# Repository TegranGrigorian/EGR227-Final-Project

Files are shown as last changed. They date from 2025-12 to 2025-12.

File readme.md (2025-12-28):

# EGR 227 Final Project

This project is a simple arcade machine using embedded microcontroller **PIC18F56Q71** to run two games: a target shooting game and a Simon Says memory game. The project utilizes various peripherals including buttons, a keypad, an LCD display, RGB LEDs, a servo motor, and a speaker to create an interactive gaming experience. This repository contains the source code, hardware schematics, and documentation for the project. Using this repository a user can build and run the arcade machine on their own hardware setup. 

## Images of the Project

### Project Model in Solidworks

This is a Solidworks assembly model of the project without any electronical components or wiring; just the 3D printed shells for the project.

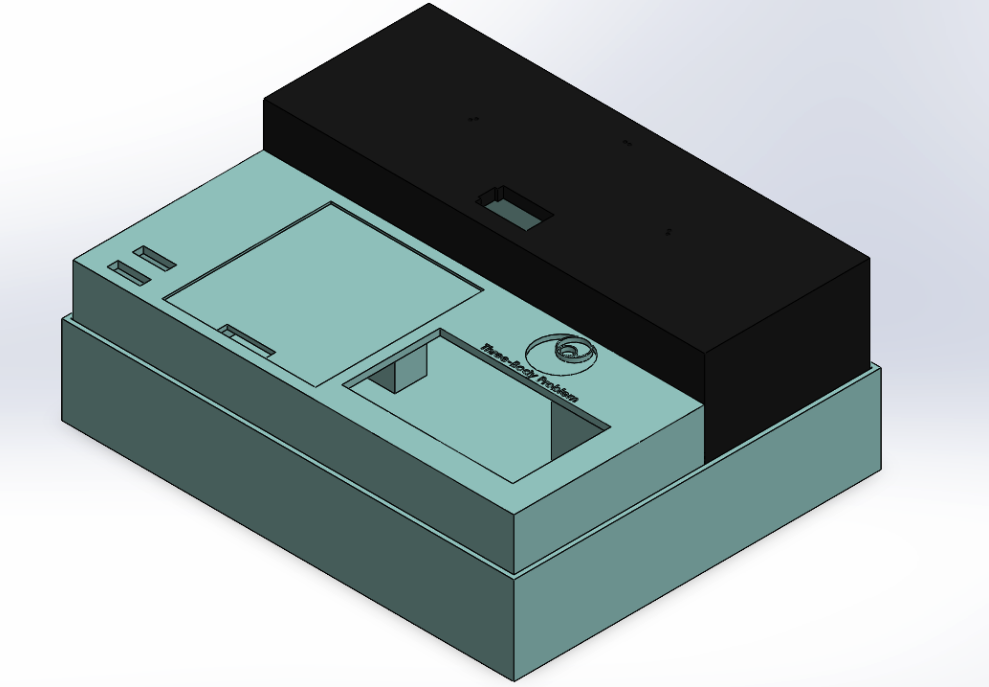
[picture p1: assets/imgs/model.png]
Project Model


### Project In Real Life

This is an image of the completed project with all the electronic components.

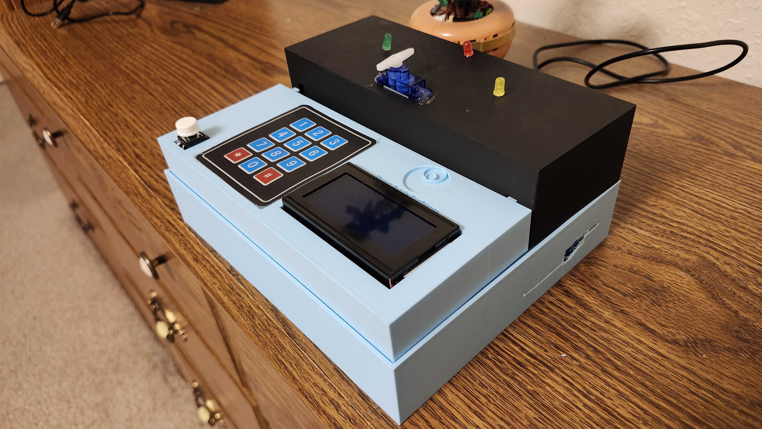
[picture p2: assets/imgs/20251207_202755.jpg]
Project Image


### Electrical Schematic

This is the electrical schematic of the project created using KICAD.

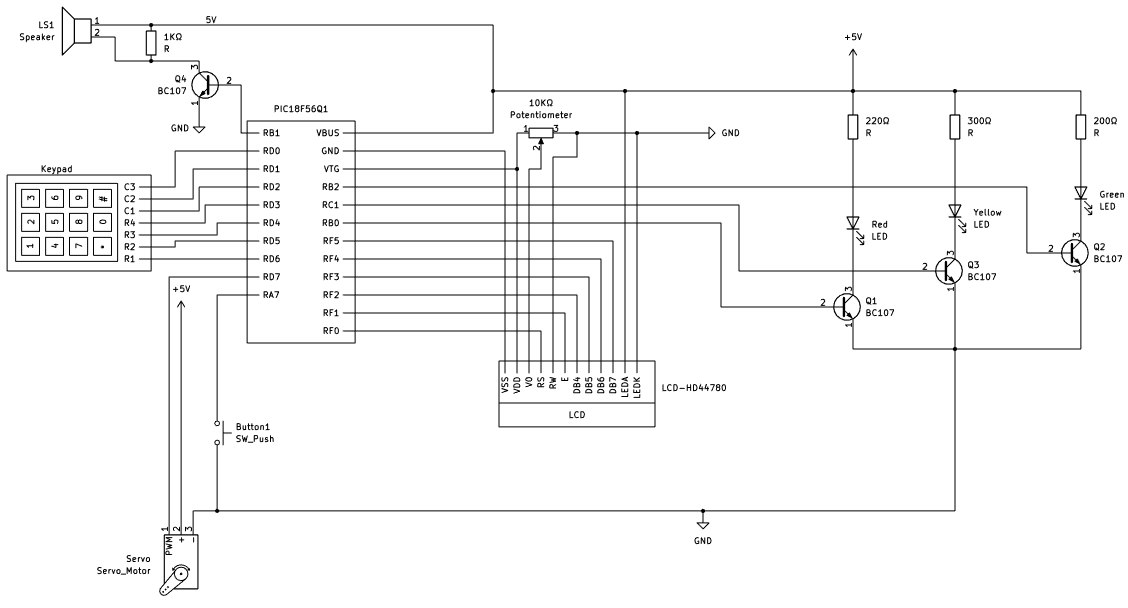
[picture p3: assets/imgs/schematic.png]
Schematic Image


### State Diagram

This is the final state diagram of the project showing all the states and transitions between them.

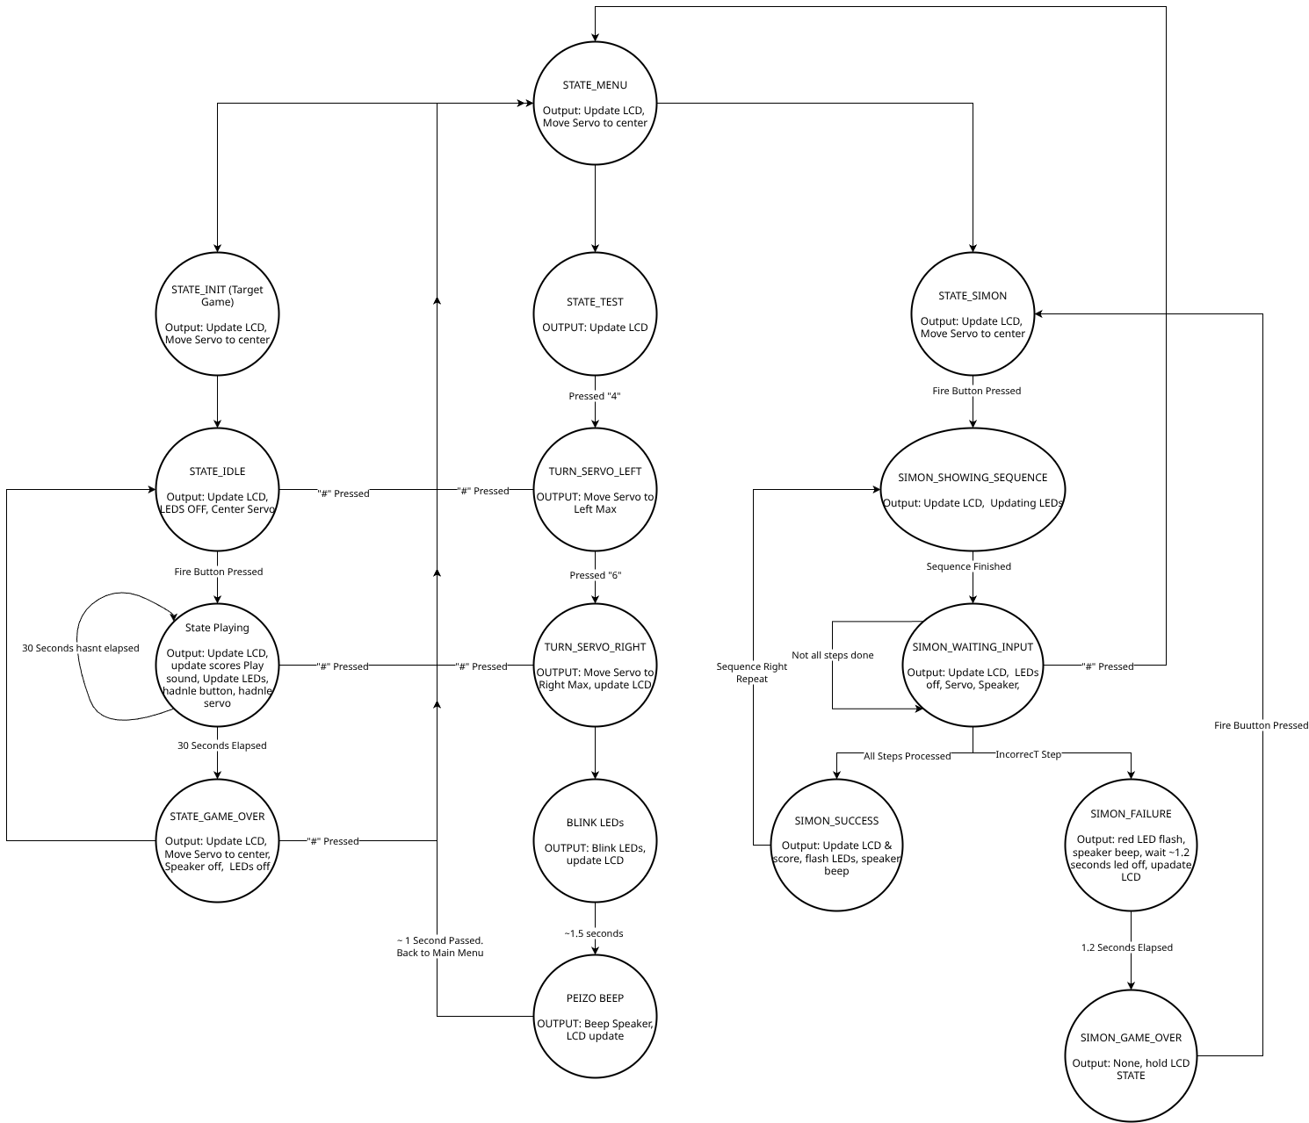
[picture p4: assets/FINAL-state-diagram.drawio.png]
State Diagram


## Project Structure

### File Tree

```
├── assets
│   ├── imgs
│   │   ├── 20251207_191956.jpg
│   │   ├── 20251207_192033.jpg
│   │   ├── 20251207_192102.jpg
│   │   ├── 20251207_192118.jpg
│   │   ├── 20251207_192130.jpg
│   │   ├── 20251207_192202.jpg
│   │   ├── 20251207_192209.jpg
│   │   ├── 20251207_192219.jpg
│   │   ├── 20251207_202755.jpg
│   │   ├── model.png
│   │   └── schematic.png
│   ├── models
│   │   ├── Assembly_all.SLDASM
│   │   ├── floor.SLDPRT
│   │   ├── floor.STL
│   │   ├── input-table.SLDPRT
│   │   ├── input-table.STL
│   │   ├── led-servo_table.SLDPRT
│   │   └── led-servo_table.STL
│   ├── FINAL-state-diagram.drawio.png
│   ├── GUI-state-diagram.drawio.png
│   ├── SIMON-state-diagram.drawio.png
│   ├── STATE_PLAYING.drawio.png
│   ├── target-game-state-diagram.drawio.png
│   └── TEST-state-diagram.drawio.png
├── schematic
│   ├── hd44780.kicad_sym
│   ├── schematic.kicad_pcb
│   ├── schematic.kicad_prl
│   ├── schematic.kicad_pro
│   └── schematic.kicad_sch
├── src
│   ├── button
│   │   ├── button.c
│   │   └── button.h
│   ├── gui
│   │   ├── gui.c
│   │   └── gui.h
│   ├── keypad
│   │   ├── keypad.c
│   │   └── keypad.h
│   ├── lcd
│   │   ├── lcd.c
│   │   └── lcd.h
│   ├── led
│   │   ├── led.c
│   │   └── led.h
│   ├── servo
│   │   ├── servo.c
│   │   └── servo.h
│   ├── simon
│   │   ├── simon.c
│   │   └── simon.h
│   ├── speaker
│   │   ├── speaker.c
│   │   └── speaker.h
│   ├── state
│   │   ├── state.c
│   │   └── state.h
│   ├── test
│   │   ├── test.c
│   │   └── test.h
│   ├── timer
│   │   ├── timer.c
│   │   └── timer.h
│   ├── hardware.h
│   ├── main.c
│   └── readme.md
├── readme.md
├── report.pdf
└── schematic.pdf
```

### Folders
- `src`: Contains all source code files for the project, including C source files and header files.
- `assets`: Contains images and state diagrams used in the project documentation.
- `schematic`: contains the KICAD schematic files for the hardware design.

### Files
- `readme.md`: This file, providing an overview of the project structure and module descriptions
- `report.pdf`: The final project report detailing the design, implementation, and testing of the project.
- `schematic.pdf`: A PDF export of the KICAD schematic for easy viewing.

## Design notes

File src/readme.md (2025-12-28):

# Project File Organization

## Directory Structure

```
├── button/
├── gui/
├── keypad/
├── lcd/
├── led/
├── servo/
├── simon/
├── speaker/
├── state/
├── test/
└── timer/
├── hardware.h
└── main.c
```

## Module Descriptions

### **button**
Handles initialization and processing of the fire button input. Provides debouncing logic and input detection to trigger game state transitions and gameplay mechanics.

### **gui**
Manages the graphical user interface state machine, including menu navigation and visual feedback. Handles state output logic and transitions between different GUI screens (splash screen, main menu, game over menu).

### **hardware.h**
Central repository for all hardware pin definitions and peripheral configurations. Provides a single source of truth for GPIO pin mappings, timer channels, PWM outputs, and device addresses used throughout the project.

### **keypad**
Implements keypad initialization and input processing for the 4x4 matrix keypad. Scans rows and columns, debounces inputs, and stores detected key presses in a structured format for game logic consumption.

### **lcd**
Provides comprehensive LCD control functions for a 16x2 character display. Includes initialization, data transmission, cursor positioning, and string writing capabilities. Manages timing delays required by HD44780 controller protocol.

### **led**
Handles RGB LED initialization and control. Includes functions to set LED colors, implement visual modes (GREEN_RED_YELLOW, YELLOW_RED_GREEN, RANDOM_STATIC), and update display patterns during gameplay. Defines LED enumeration types for mode selection.

### **main.c**
Contains the primary state machine orchestrator that coordinates the entire program flow. Initializes all peripherals and executes the main game loop, dispatching to appropriate handlers based on current program state.

### **servo**
Manages servo motor initialization and position control via PWM. Stores an array of predefined servo positions (POS_1 through POS_5) and provides functions to update duty cycles, enabling dynamic servo movement during gameplay.

### **simon**
Implements the Simon Says memory game logic. Contains initialization code to reset game state, multiple state handlers for game phases (SHOWING_SEQUENCE, WAITING_INPUT, SUCCESS, FAILURE), and a holistic game orchestrator that manages the complete Simon Says gameplay loop.

### **speaker**
Handles speaker initialization and audio control via PWM frequency modulation. Provides functions to generate sound effects and tones of varying frequencies and durations, used by both the target game and Simon Says game for audio feedback.

### **state**
Implements the target game state machine with four primary states (INIT, IDLE, PLAYING, GAME_OVER). Includes state handler functions that manage game initialization, idle waiting, active gameplay, and score display. Coordinates interactions with LED, servo, speaker, keypad, and LCD modules.

### **test**
Contains hardware diagnostic and testing functions that verify proper operation of all peripheral devices including buttons, keypads, LEDs, servos, speakers, and LCD displays. Used for development debugging and hardware validation.

### **timer**
Manages timer initialization and interrupt handling. Implements Timer 0 for precise 10 ms interrupt generation (100 interrupts per second), Timer 1 for blocking delays, and Timer 2/4 for PWM control. The Timer 0 ISR enforces the 30-second game duration by counting elapsed seconds.

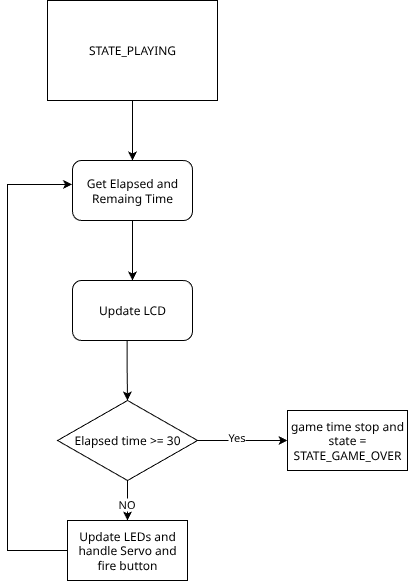
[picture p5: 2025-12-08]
assets/STATE_PLAYING.drawio.png

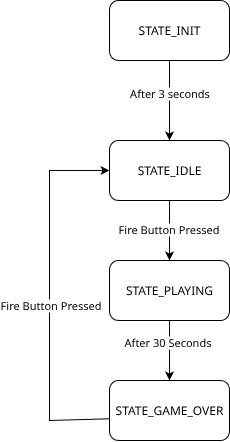
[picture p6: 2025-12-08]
assets/target-game-state-diagram.drawio.png

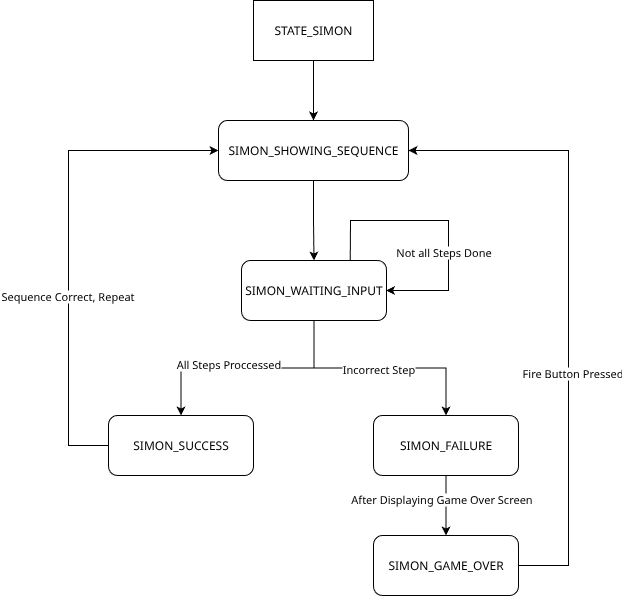
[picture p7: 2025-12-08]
assets/SIMON-state-diagram.drawio.png

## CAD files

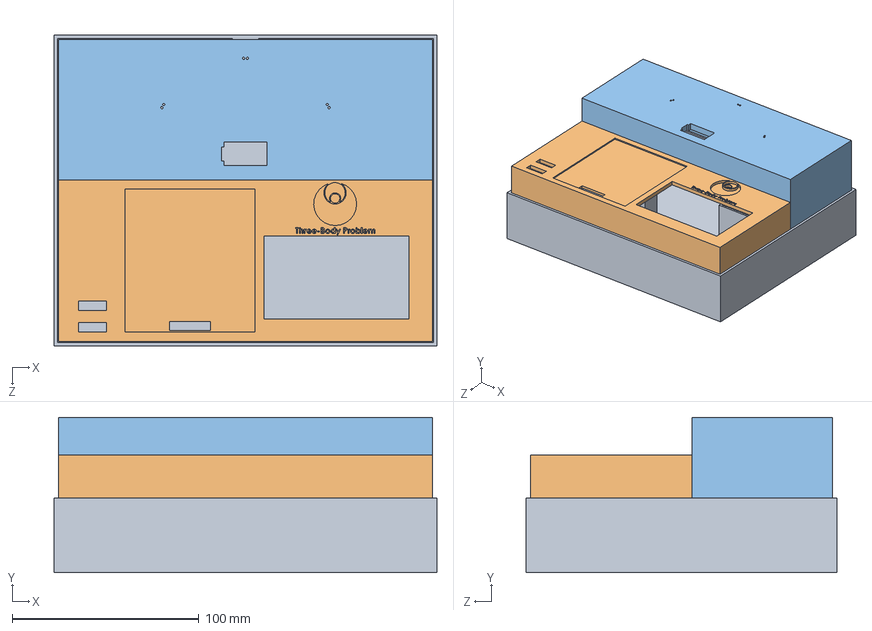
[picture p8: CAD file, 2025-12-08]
assets/models/Assembly_all.SLDASM
205.0 x 83.0 x 166.5 mm
led-servo_table
input-table
floor

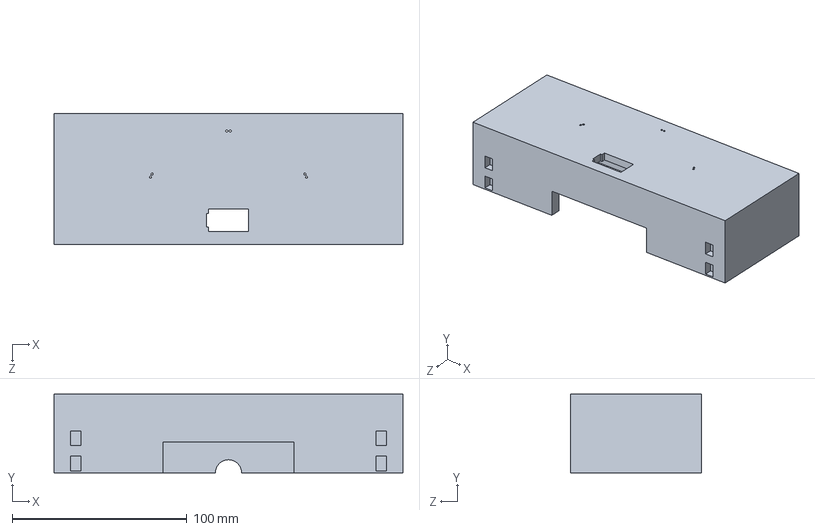
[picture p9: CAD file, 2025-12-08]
assets/models/led-servo_table.SLDPRT
200.0 x 45.0 x 75.0 mm

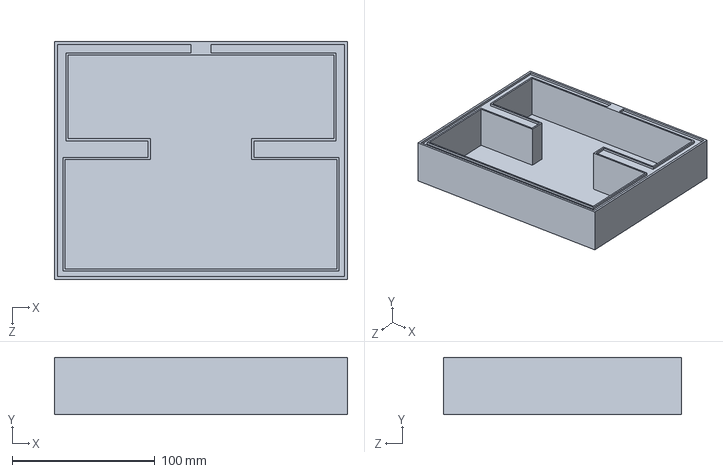
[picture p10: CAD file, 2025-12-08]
assets/models/floor.SLDPRT
205.0 x 40.0 x 166.5 mm

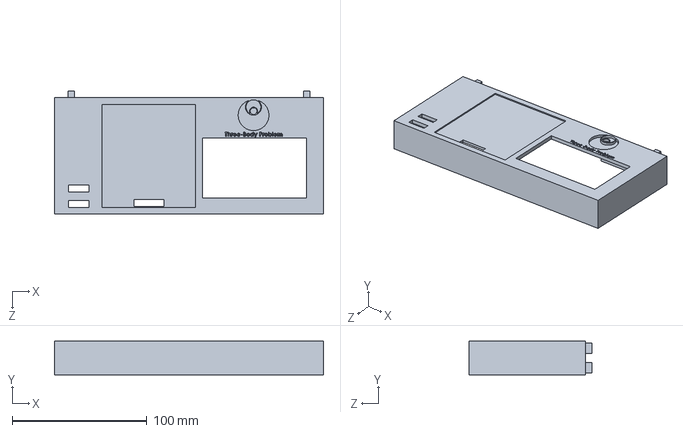
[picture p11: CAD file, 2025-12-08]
assets/models/input-table.SLDPRT
200.0 x 25.0 x 91.5 mm

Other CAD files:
assets/models/floor.STL
assets/models/input-table.STL
assets/models/led-servo_table.STL

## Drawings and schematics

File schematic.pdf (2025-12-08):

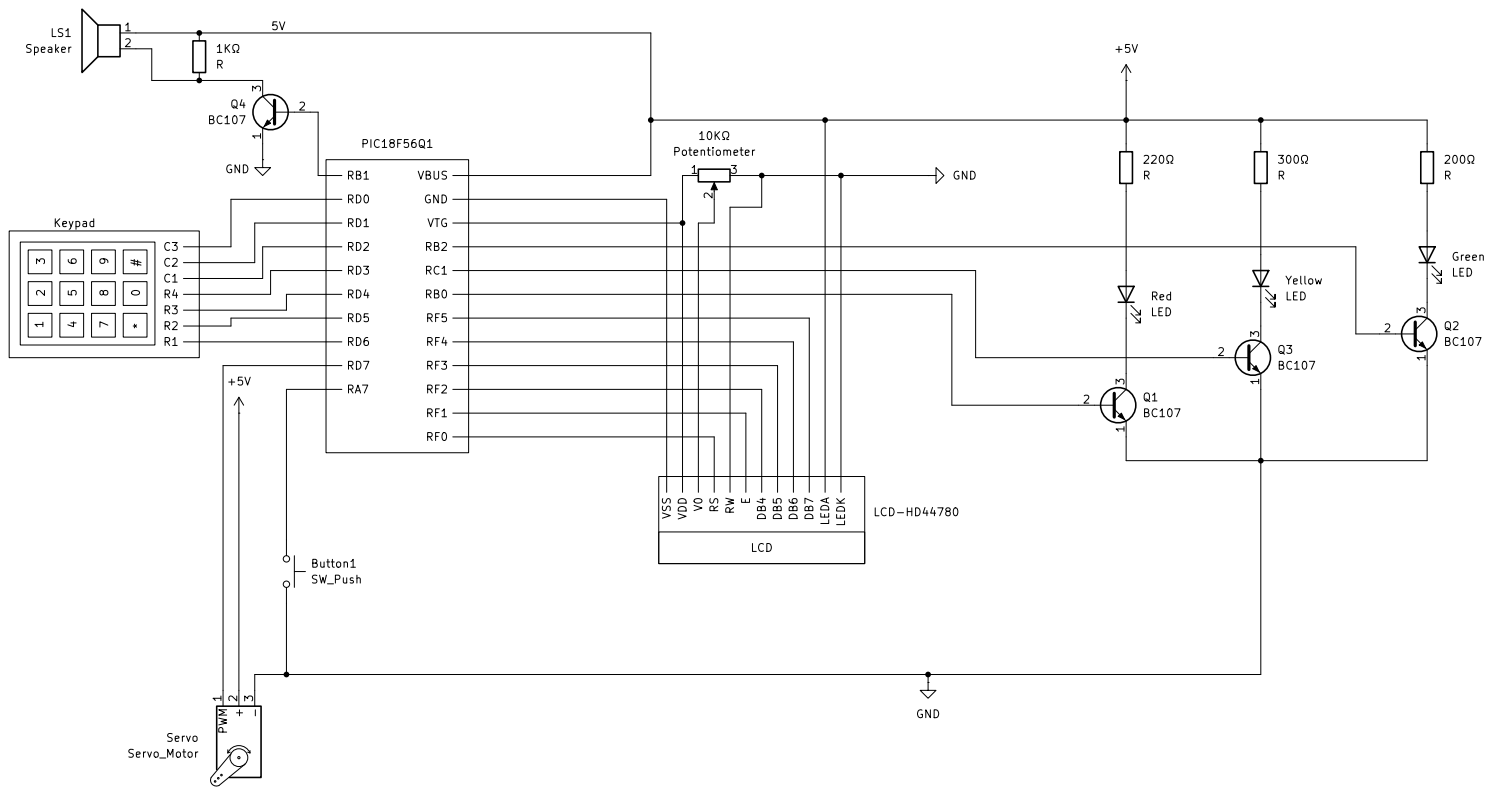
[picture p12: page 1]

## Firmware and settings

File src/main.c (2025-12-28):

#include "hardware.h"
#include <xc.h>
#include <stdio.h>
#include <stdlib.h>
#include <time.h>
#include "state/state.h"
#include "lcd/lcd.h"
#include "servo/servo.h"
#include "button/button.h"
#include "keypad/keypad.h"
#include "timer/timer.h"
#include "speaker/speaker.h"
#include "led/led.h"
#include "gui/gui.h"
#include "servo/servo.h"

#define _XTAL_FREQ 4000000
#pragma config WDTE = OFF       

void system_init(void) { // holy initalize
    GPIO_Init(); // gpio for the LCD 
    init_leds();
    init_speaker();
    init_onboard_led(); // debug led
    init_keypad();
    buttons_init();
    servo_init();
    LCD_init();
    game_timer_init(); // Timer0 for game timing
    srand(42);  // 42 is the answer to the univese
}

void main(void) {
    system_init();
    GameState game; // game state machine structure
    init_game_state(&game); // initalize the game state strucutre/vars
    
    // main loop
    while(1) {
        switch(game.current_state) { // state machine current state structure organizer
            case STATE_MENU: // main menu screen
                gui_menu_handler(&game);
                break;
                
            case STATE_INIT: // initial game state
                state_init_handler(&game);
                break;
                
            case STATE_IDLE: // idle waiting for fire button to go
                state_idle_handler(&game);
                break;
                
            case STATE_PLAYING: // pew pew
                state_playing_handler(&game);
                break;
                
            case STATE_GAME_OVER: // game over
                state_game_over_handler(&game);
                break;
                
            case STATE_TEST: //  test screen, option 3
                gui_test_handler(&game);
                break;
                
            case STATE_SIMON_SAYS: // Simon Says, option 2
                gui_simon_handler(&game);
                break;
                
            default: // just in case a oopsie occurs
                game.current_state = STATE_MENU;
                break;
        }
    }
}

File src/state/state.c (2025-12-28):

#include "state.h"
#include "../hardware.h"
#include "../lcd/lcd.h"
#include "../servo/servo.h"
#include "../button/button.h"
#include "../keypad/keypad.h"
#include "../timer/timer.h"
#include "../speaker/speaker.h"
#include "../led/led.h"
#include "../test/test.h"
#include <stdlib.h>
#include <stdio.h>
#include <string.h>

#define _XTAL_FREQ 4000000

void init_game_state(GameState *game) { // initalize alll game strucutre variables
    game->current_state = STATE_MENU;  
    game->hits = 0;
    game->misses = 0;
    game->time_remaining = 30;
    game->servo_pos = POS_3;  
    game->led_mode = MODE_GREEN_RED_YELLOW;
    game->current_led = 3;  
    game->led_sequence_step = 0;
    game->led_timer = 0;
    game->prev_fire_button = read_button1();  
}

void reset_game_state(GameState *game) { // reset game state variables for new game
    game->hits = 0;
    game->misses = 0;
    game->time_remaining = 30;
    game->led_sequence_step = 0;
    game->led_timer = 0;
    game->current_led = 3;
    all_leds_off();
    select_random_led_mode(game);
}

void state_init_handler(GameState *game) { // initial game state handler
    static uint32_t init_timer = 0;
    static char screen_written = 0;  
    
    if (!screen_written) { // 3 second delay with the title screen :)
        write_command(0x01);  
        __delay_ms(10);
        write_string("  TARGET  FUN  ", 1);
        write_string("   EGR 227     ", 2);
        write_string("Tegran Grigorian", 4);
        screen_written = 1;
        init_timer = 0;  
        
        servo_set_duty_cycle(servo_position_to_duty_cycle(POS_3)); // make sure servo is centered and ready
    }
    
    init_timer++; // increment timer every ms
    if (init_timer % 125 == 0) {
        LATC ^= 0x80;  
    }
    speaker_off(); // the peizo is so annoying
    if (init_timer >= 3000) { // 3 seconds elapsed
        LATC &= ~0x80; /// debug led off
        write_command(0x01);  
        __delay_ms(10); // wait for LCD to clear
        write_string("HITS:0  TIME:30", 1);
        write_string("MISSES:0       ", 2);
        game->current_state = STATE_IDLE; // move to idle state
        screen_written = 0;
        init_timer = 0;
    }
}

void state_idle_handler(GameState *game) {
    static char servo_centered = 0;  
    keypad key = numpad_press();
    if (key.pressed) { // if pressed, check for #
        uint8_t key_num = numpad_value(key.cols, key.rows);
        if (key_num == 12) {  // if # is pressed go back to main menu
            servo_centered = 0;
            all_leds_off();
            game->current_state = STATE_MENU;
            return;
        }
    }
    LATC &= ~0x80; // flash debug led off
    speaker_off(); // just to make sure this piece of poop is off
    if (!servo_centered) { // if it isnt centered, (just in case) center it
        game->servo_pos = POS_3;  
        servo_set_duty_cycle(servo_position_to_duty_cycle(POS_3));
        servo_centered = 1;
    }
    
    char fire_button = read_button1();
    if (fire_button && !game->prev_fire_button) { // check if the user starts the game
        LATC |= 0x80;  // debug led on
        reset_game_state(game); // reset game variabels
        game->current_state = STATE_PLAYING; // move to playing state
        game->led_timer = 0;
        game->time_remaining = 30; // just in case
        game_timer_reset(); // reset and start game timer
        game_timer_start(); // start game timer
        reset_led_timer_tracker();  // reset led timer tracker
        servo_centered = 0; // center again
        game->prev_fire_button = fire_button; // wipe previous button state
        return;  
    }
    game->prev_fire_button = fire_button; // update previous button state
}

void state_playing_handler(GameState *game) {
    // vars
    uint8_t elapsed = game_timer_get_seconds();
    uint8_t remaining = (elapsed >= 30) ? 0 : (30 - elapsed);
    LATC &= ~0x80; // debug led off
    speaker_off(); // start with speaker off
    
    game->time_remaining = remaining; // update time remaining
    update_lcd_game_screen(game); // update the lcd to show that
    
    if (elapsed >= 30 || !game_timer_is_running()) { // time is up
        game->current_state = STATE_GAME_OVER; // bye
        game_timer_stop(); // everything resets
        all_leds_off();
        return; // lave function so main loop can move us to game over
    }

    // handle game components
    update_led_targets(game);
    handle_servo_movement(game);
    handle_fire_button(game);
}

void state_game_over_handler(GameState *game) {
    keypad key = numpad_press(); // check keypad for # again
    if (key.pressed) {
        uint8_t key_num = numpad_value(key.cols, key.rows);
        if (key_num == 12) {  
            all_leds_off();
            game->current_state = STATE_MENU;
            return;
        }
    }

    all_leds_off(); // everything off
    game->time_remaining = 0; // sometimes the LCD would show a 1, so to ensrue we stop and print that, lets force it to be 0
    update_lcd_game_screen(game); // update lcd one last time
    speaker_off(); // please be off

    char fire_button = read_button1();
    if (fire_button && !game->prev_fire_button) { // check fire button to see if user wants to play again
        game->current_state = STATE_IDLE;
        reset_game_state(game);
        update_lcd_game_screen(game);
        game->prev_fire_button = fire_button;
        return;  
    }
    game->prev_fire_button = fire_button; // update previous button state
}

void update_lcd_game_screen(GameState *game) {
    char line1[17]; // 16 chars + null
    char line2[17];
    
    // buffers for each line
    sprintf(line1, "HITS:%-2d TIME:%-2d ", game->hits, game->time_remaining);
    sprintf(line2, "MISSES:%-2d      ", game->misses);
    
    // write the buffers to the LCD
    write_string(line1, 1);
    write_string(line2, 2);
}
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

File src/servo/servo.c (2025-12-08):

#include "servo.h"
#include "hardware.h"

// Define constants
#define FOSC 4000000
#define TIMER_PRESCALER 7
#define T4_PERIOD_REG 155

// Servo position duty cycle mappings
const uint8_t SERVO_POSITIONS[5] = {42, 58, 75, 92, 108};
uint8_t current_duty_cycle = 75;  

void servo_init(void) { // port setup, timer4 setup, ccp2 setup for pwm, duty cycle init
    ANSELD &= ~SERVO;
    TRISD &= ~SERVO;
    LATD &= ~SERVO;
    T4CON = 0x00;
    T4TMR = 0x00;
    T4CLKCON = 0x01;
    T4PR = T4_PERIOD_REG;      
    T4CON = (TIMER_PRESCALER << 4);
    CCPTMRS0 &= ~0x0C;
    CCPTMRS0 |= 0x08;
    CCP2CON = 0x00;
    CCP2CON = 0x8C;
    RD7PPS = 0x0E;
    uint16_t ccpr_value = (((uint32_t)75 * 156) / 1000) << 2;
    CCPR2 = ccpr_value;
    current_duty_cycle = 75;
    T4CON |= 0x80;                       
}

int8_t servo_set_duty_cycle(uint8_t duty_cycle) { // set servo duty cycle, return -1 ifout of bounds
    if (duty_cycle < SERVO_MIN_DC || duty_cycle > SERVO_MAX_DC) {
        return -1;  
    }   
    uint16_t ccpr_value; // calculate CCPR2 value for desired duty cycle
    ccpr_value = (((uint32_t)duty_cycle * 156) / 1000) << 2; // ccpr_value = (duty_cycle% * 156) / 1000 * 4
    CCPR2 = ccpr_value;
    current_duty_cycle = duty_cycle;
    return 0;
}

uint8_t servo_get_duty_cycle(void) { // get current servo duty cycle
    return current_duty_cycle;
}

uint8_t clamp_servo_duty_cycle(uint8_t duty_cycle) { // clamp duty cycle to min/max limits
    if (duty_cycle < SERVO_MIN_DC) {
        return SERVO_MIN_DC;
    } else if (duty_cycle > SERVO_MAX_DC) {
        return SERVO_MAX_DC;
    } else {
        return duty_cycle;
    }
}

uint8_t servo_position_to_duty_cycle(ServoPosition pos) { // convert servo position enum to duty cycle
    return SERVO_POSITIONS[pos];
}

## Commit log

2025-12-08 Commit entire repo
    [schematic.kicad_pcb, schematic.kicad_sch]
2025-12-08 Added sldprt and stls of models
    [Assembly_all.SLDASM, floor.SLDPRT, floor.STL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]
